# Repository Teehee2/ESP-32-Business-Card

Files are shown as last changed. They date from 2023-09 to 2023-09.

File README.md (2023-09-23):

# ESP-32-Business-Card
Personal Business Card with fully functional ESP-32 and NFC

Latest version V0.2

Friends with version V0.1: PLEASE TAKE NOTE!
DO NOT USE CLIP POINT USB 5V! IT WILL SHORT TO GROUND!

For DIY users:
V0.1 is flawed with mixed up tx/rx traces! Enamel wires need to be flown to use ESP32!
SW1 does not work with resistor R9, it is recommended to short the pads across R9.

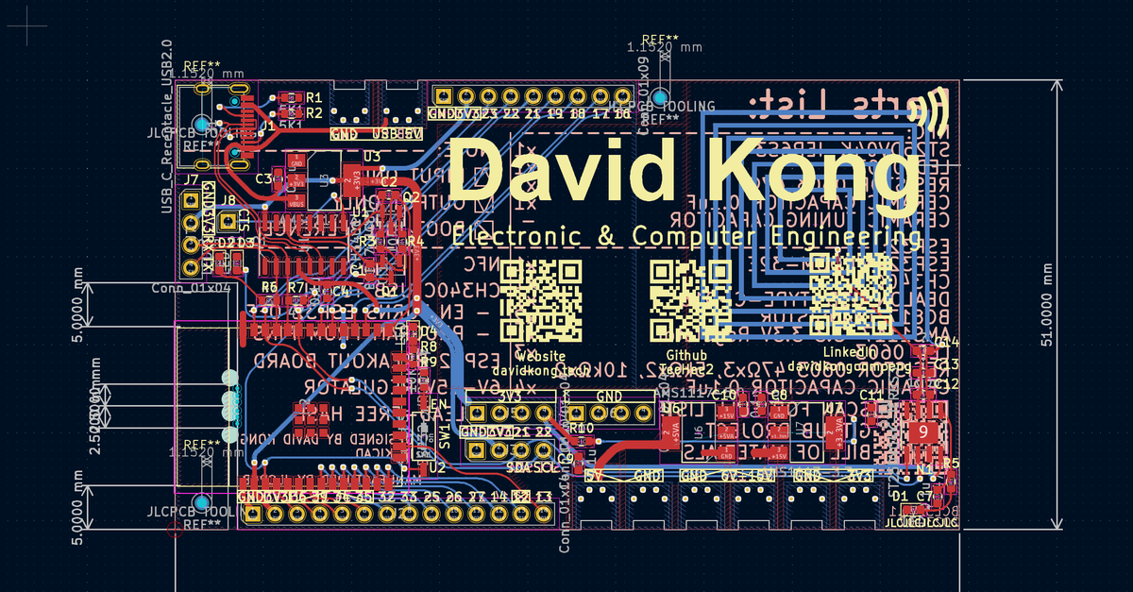
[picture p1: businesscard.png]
ESP32 Business Card


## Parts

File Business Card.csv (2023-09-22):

Source: | D:\PCB projects\Business Card - ESP32\Business Card\Business Card.kicad_sch
Date: | 2023/7/2 22:13:04
Tool: | Eeschema 7.0.5
Generator: | D:\Kicad\7.0\bin\scripting\plugins/bom_csv_grouped_by_value.py
Component Count: | 44
Collated Components:
Item | Qty | Reference(s) | Value | LibPart | Footprint | Datasheet | DNP | Arrow Part Number | Arrow Price/Stock | Height | Manufacturer_Name | Manufacturer_Part_Number | Mouser Part Number | Mouser Price/Stock
1 | 1 | AE1 | ~ | Custom-Symbols:NFC_Antenna | Custom footprints:NFC2
2 | 9 | C1, C2, C3, C4, C7, C8, C9, C10, C11 | 0.1u | Device:C | Capacitor_SMD:C_0201_0603Metric | ~
3 | 1 | C12 | 100p | Device:C | Capacitor_SMD:C_0201_0603Metric | ~
4 | 2 | C13, C14 | ? | Device:C | Capacitor_SMD:C_0201_0603Metric | ~
5 | 4 | D1, D2, D3, D4 | LED | Device:LED | LED_SMD:LED_0201_0603Metric | ~
6 | 1 | J1 | USB_C_Receptacle_USB2.0 | Connector:USB_C_Receptacle_USB2.0 | Connector_USB:USB_C_Receptacle_HRO_TYPE-C-31-M-12 | https://www.usb.org/sites/default/files/documents/usb_type-c.zip
7 | 1 | J2 | Conn_01x14 | Connector_Generic:Conn_01x14 | Custom footprints:PinHeader_1x14_P2.54mm_Vertical_1_No_Silk | ~
8 | 4 | J3, J5, J6, J7 | Conn_01x04 | Connector_Generic:Conn_01x04 | Custom footprints:PinHeader_1x04_P2.54mm_Vertical_No_Silk | ~
9 | 1 | J4 | Conn_01x09 | Connector_Generic:Conn_01x09 | Custom footprints:PinHeader_1x09_P2.54mm_Vertical_No_Silk | ~
10 | 1 | J8 | Conn_01x01 | Connector_Generic:Conn_01x01 | Connector_PinHeader_2.54mm:PinHeader_1x01_P2.54mm_Vertical | ~
11 | 1 | N1 | ST25DV04K-IER6S3 | ST25DV04K-IER6S3:ST25DV04K-IER6S3 | Package_SO:SOIC-8-1EP_3.9x4.9mm_P1.27mm_EP2.41x3.3mm | https://ms.componentsearchengine.com/Datasheets/2/ST25DV04K-IER6S3.pdf |  | ST25DV04K-IER6S3 | https://www.arrow.com/en/products/st25dv04k-ier6s3/stmicroelectronics?region=europe | 1.75 | STMicroelectronics | ST25DV04K-IER6S3 | 511-ST25DV04K-IER6S3 | https://www.mouser.co.uk/ProductDetail/STMicroelectronics/ST25DV04K-IER6S3?qs=xjeEZJU9OeNdtP1j9447OQ%3D%3D
12 | 2 | Q1, Q2 | BC817 | Transistor_BJT:BC817 | Package_TO_SOT_SMD:SOT-23 | https://www.onsemi.com/pub/Collateral/BC818-D.pdf
13 | 2 | R1, R2 | 5K1 | Device:R | Resistor_SMD:R_0201_0603Metric | ~
14 | 3 | R3, R4, R9 | 10K | Device:R | Resistor_SMD:R_0201_0603Metric | ~
15 | 4 | R5, R6, R7, R8 | 47 | Device:R | Resistor_SMD:R_0201_0603Metric | ~
16 | 1 | R10 | 0 | Device:R | Resistor_SMD:R_0201_0603Metric | ~
17 | 1 | SW1 | SW_SPST | Switch:SW_SPST | Button_Switch_SMD:SW_DIP_SPSTx01_Slide_Copal_CHS-01B_W7.62mm_P1.27mm | ~
18 | 1 | U1 | CH340C | Interface_USB:CH340C | Package_SO:SOIC-16_3.9x9.9mm_P1.27mm | https://datasheet.lcsc.com/szlcsc/Jiangsu-Qin-Heng-CH340C_C84681.pdf
19 | 1 | U2 | ESP32-WROOM-E | PCM_Espressif:ESP32-WROOM-E | PCM_Espressif:ESP32-WROOM-32E | https://www.espressif.com/sites/default/files/documentation/esp32-wroom-32e_esp32-wroom-32ue_datasheet_en.pdf
20 | 2 | U3, U7 | AMS1117-3.3 | Regulator_Linear:AMS1117-3.3 | Package_TO_SOT_SMD:SOT-223-3_TabPin2 | http://www.advanced-monolithic.com/pdf/ds1117.pdf
21 | 1 | U6 | AMS1117-5.0 | Regulator_Linear:AMS1117-5.0 | Package_TO_SOT_SMD:SOT-223-3_TabPin2 | http://www.advanced-monolithic.com/pdf/ds1117.pdf

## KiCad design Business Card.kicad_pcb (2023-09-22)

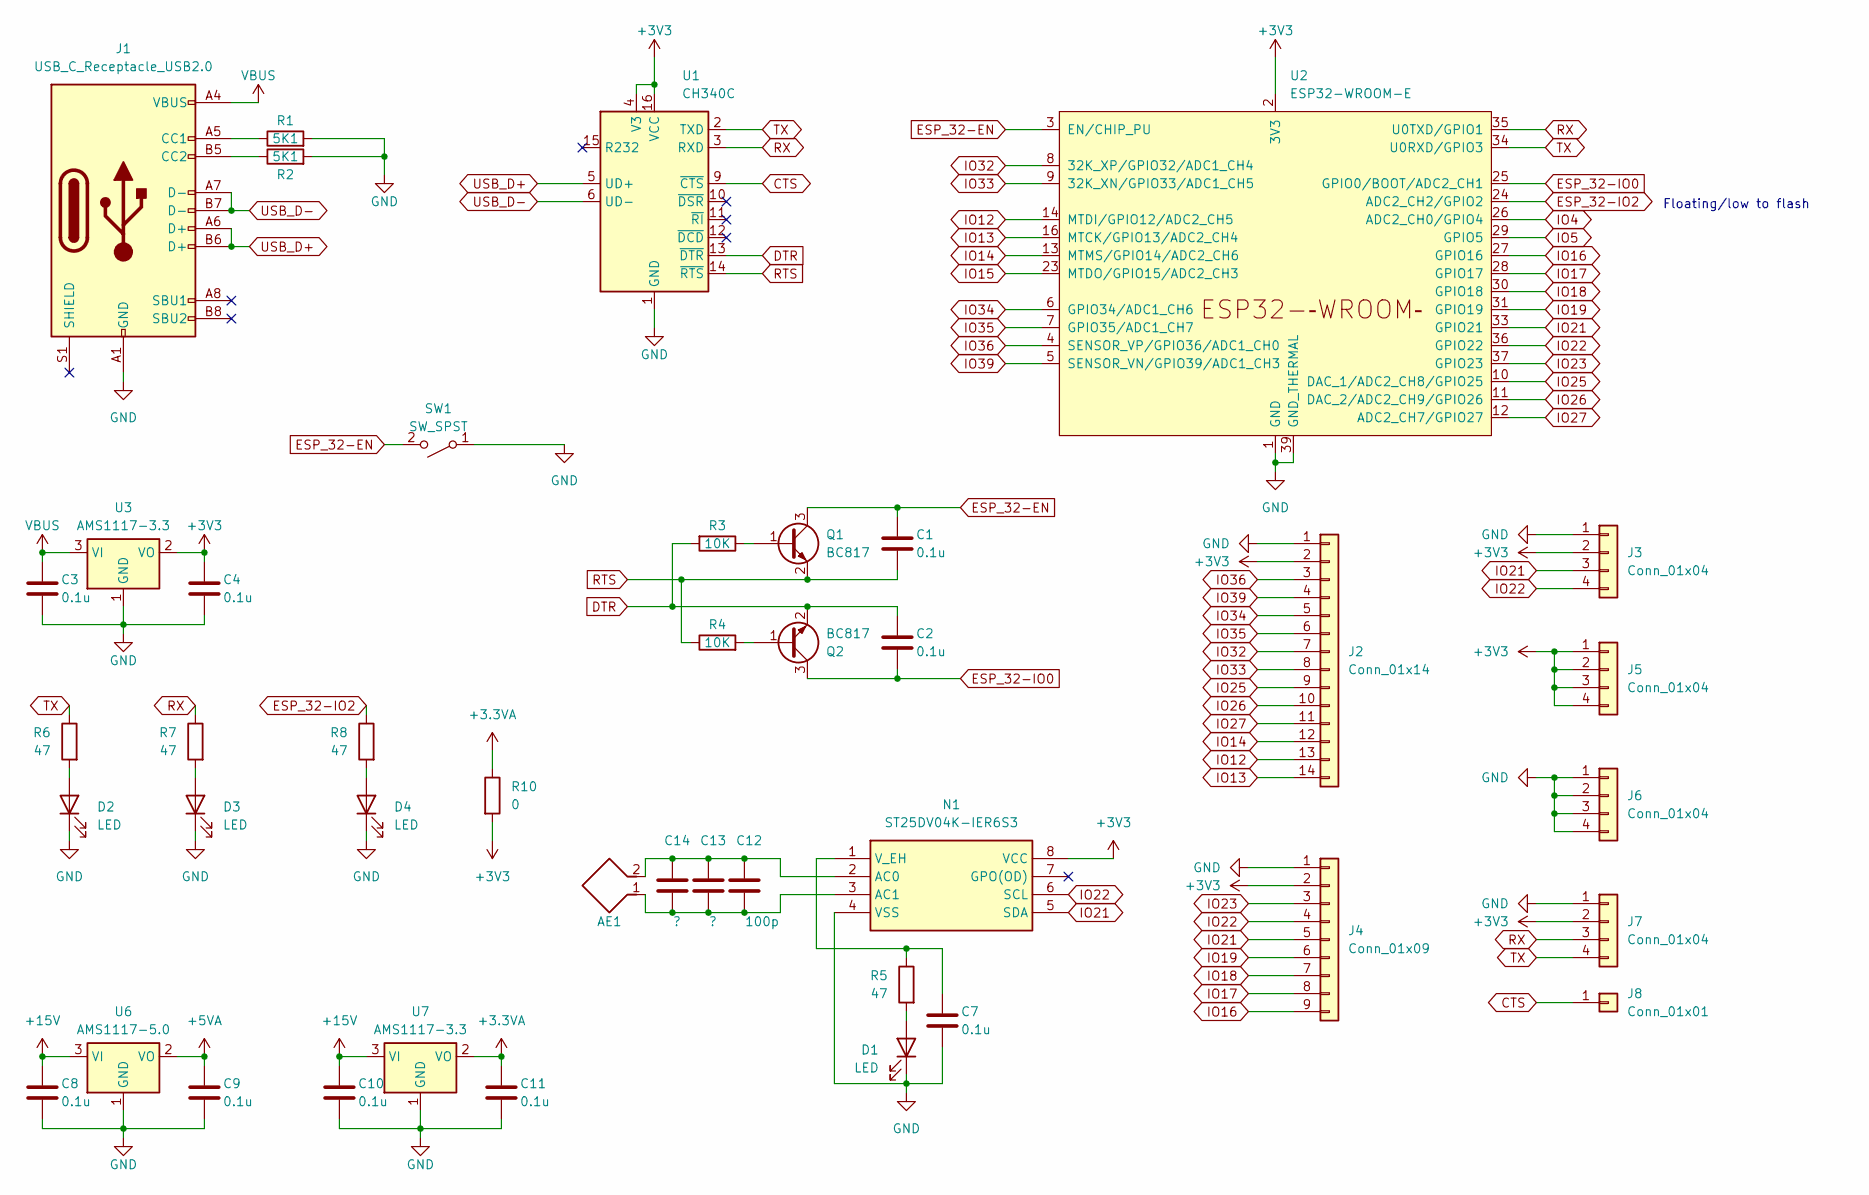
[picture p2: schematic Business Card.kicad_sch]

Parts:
AE1: NFC2
C1, C2, C3, C4, C7, C8, C9, C10, C11: 0.1u; C_0603_1608Metric
C12: 100p; C_0603_1608Metric
C13, C14: ?; C_0603_1608Metric
D1, D2, D3, D4: LED; LED_0603_1608Metric
J1: USB_C_Receptacle_USB2.0; USB_C_Receptacle_HRO_TYPE-C-31-M-12
J2: Conn_01x14; PinHeader_1x14_P2.54mm_Vertical_1_No_Silk
J3, J5, J6, J7: Conn_01x04; PinHeader_1x04_P2.54mm_Vertical_No_Silk
J4: Conn_01x09; PinHeader_1x09_P2.54mm_Vertical_No_Silk
J8: Conn_01x01; PinHeader_1x01_P2.54mm_Vertical_No_Silk
N1: ST25DV04K-IER6S3; SOIC-8-1EP_3.9x4.9mm_P1.27mm_EP2.41x3.3mm; Manufacturer_Part_Number ST25DV04K-IER6S3; Mouser Part Number 511-ST25DV04K-IER6S3
Q1, Q2: BC817; SOT-23
R1, R2: 5K1; R_0603_1608Metric
R3, R4: 10K; R_0603_1608Metric
R5, R6, R7, R8: 47; R_0603_1608Metric
R10: 0; R_0603_1608Metric
SW1: SW_SPST; SW_DIP_SPSTx01_Slide_Copal_CHS-01B_W7.62mm_P1.27mm
U1: CH340C; SOIC-16_3.9x9.9mm_P1.27mm
U2: ESP32-WROOM-E; ESP32-WROOM-32E
U3, U7: AMS1117-3.3; SOT-223-3_TabPin2
U6: AMS1117-5.0; SOT-223-3_TabPin2

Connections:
+3.3VA: C11.1, R10.1, U7.2 (VO)
+3V3: C4.1, J2.2, J3.2, J4.2, J5.1, J5.2, J5.3, J5.4, J7.2, N1.8 (VCC), R10.2, U1.4 (V3), U1.16 (VCC), U2.2 (3V3), U3.2 (VO)
+5VA: C9.1, U6.2 (VO)
+15V: C8.1, C10.1, U6.3 (VI), U7.3 (VI)
CTS: J8.1, U1.9 (~CTS)
DTR: C2.1, Q2.2 (E), R3.2, U1.13 (~DTR)
ESP_32-EN: C1.1, Q1.3 (C), SW1.2 (B), U2.3 (EN/CHIP_PU)
ESP_32-IO0: C2.2, Q2.3 (C), U2.25 (GPIO0/BOOT/ADC2_CH1)
ESP_32-IO2: R8.1, U2.24 (ADC2_CH2/GPIO2)
GND: C3.2, C4.2, C7.2, C8.2, C9.2, C10.2, C11.2, D1.1 (K), D2.1 (K), D3.1 (K), D4.1 (K), J1.A1 (GND), J1.A12 (GND), J1.B1 (GND), J1.B12 (GND), J2.1, J3.1, J4.1, J6.1, J6.2, J6.3, J6.4, J7.1, N1.4 (VSS), R1.2, R2.2, SW1.1 (A), U1.1 (GND), U2.1 (GND), U2.15 (GND), U2.38 (GND), U2.39 (GND_THERMAL), U3.1 (GND), U6.1 (GND), U7.1 (GND); also elsewhere on the board
IO4: U2.26 (ADC2_CH0/GPIO4)
IO5: U2.29 (GPIO5)
IO12: J2.13, U2.14 (MTDI/GPIO12/ADC2_CH5)
IO13: J2.14, U2.16 (MTCK/GPIO13/ADC2_CH4)
IO14: J2.12, U2.13 (MTMS/GPIO14/ADC2_CH6)
IO15: U2.23 (MTDO/GPIO15/ADC2_CH3)
IO16: J4.9, U2.27 (GPIO16)
IO17: J4.8, U2.28 (GPIO17)
IO18: J4.7, U2.30 (GPIO18)
IO19: J4.6, U2.31 (GPIO19)
IO21: J3.3, J4.5, N1.5 (SDA), U2.33 (GPIO21)
IO22: J3.4, J4.4, N1.6 (SCL), U2.36 (GPIO22)
IO23: J4.3, U2.37 (GPIO23)
IO25: J2.9, U2.10 (DAC_1/ADC2_CH8/GPIO25)
IO26: J2.10, U2.11 (DAC_2/ADC2_CH9/GPIO26)
IO27: J2.11, U2.12 (ADC2_CH7/GPIO27)
IO32: J2.7, U2.8 (32K_XP/GPIO32/ADC1_CH4)
IO33: J2.8, U2.9 (32K_XN/GPIO33/ADC1_CH5)
IO34: J2.5, U2.6 (GPIO34/ADC1_CH6)
IO35: J2.6, U2.7 (GPIO35/ADC1_CH7)
IO36: J2.3, U2.4 (SENSOR_VP/GPIO36/ADC1_CH0)
IO39: J2.4, U2.5 (SENSOR_VN/GPIO39/ADC1_CH3)
unnamed: D1.2 (A), R5.2
unnamed: D2.2 (A), R6.2
unnamed: D3.2 (A), R7.2
unnamed: D4.2 (A), R8.2
unnamed: J1.A5 (CC1), R1.1
unnamed: J1.B5 (CC2), R2.1
unnamed: AE1.2, C12.1, C13.1, C14.1, N1.2 (AC0)
unnamed: AE1.1, C12.2, C13.2, C14.2, N1.3 (AC1)
unnamed: C7.1, N1.1 (V_EH), R5.1
unnamed: Q1.1 (B), R3.1
unnamed: Q2.1 (B), R4.2
RTS: C1.2, Q1.2 (E), R4.1, U1.14 (~RTS)
RX: J7.3, R7.1, U1.3 (RXD), U2.35 (U0TXD/GPIO1)
TX: J7.4, R6.1, U1.2 (TXD), U2.34 (U0RXD/GPIO3)
USB_D+: J1.A6 (D+), J1.B6 (D+), U1.5 (UD+)
USB_D-: J1.A7 (D-), J1.B7 (D-), U1.6 (UD-)
VBUS: C3.1, J1.A4 (VBUS), J1.A9 (VBUS), J1.B4 (VBUS), J1.B9 (VBUS), U3.3 (VI)

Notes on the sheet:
Floating/low to flash

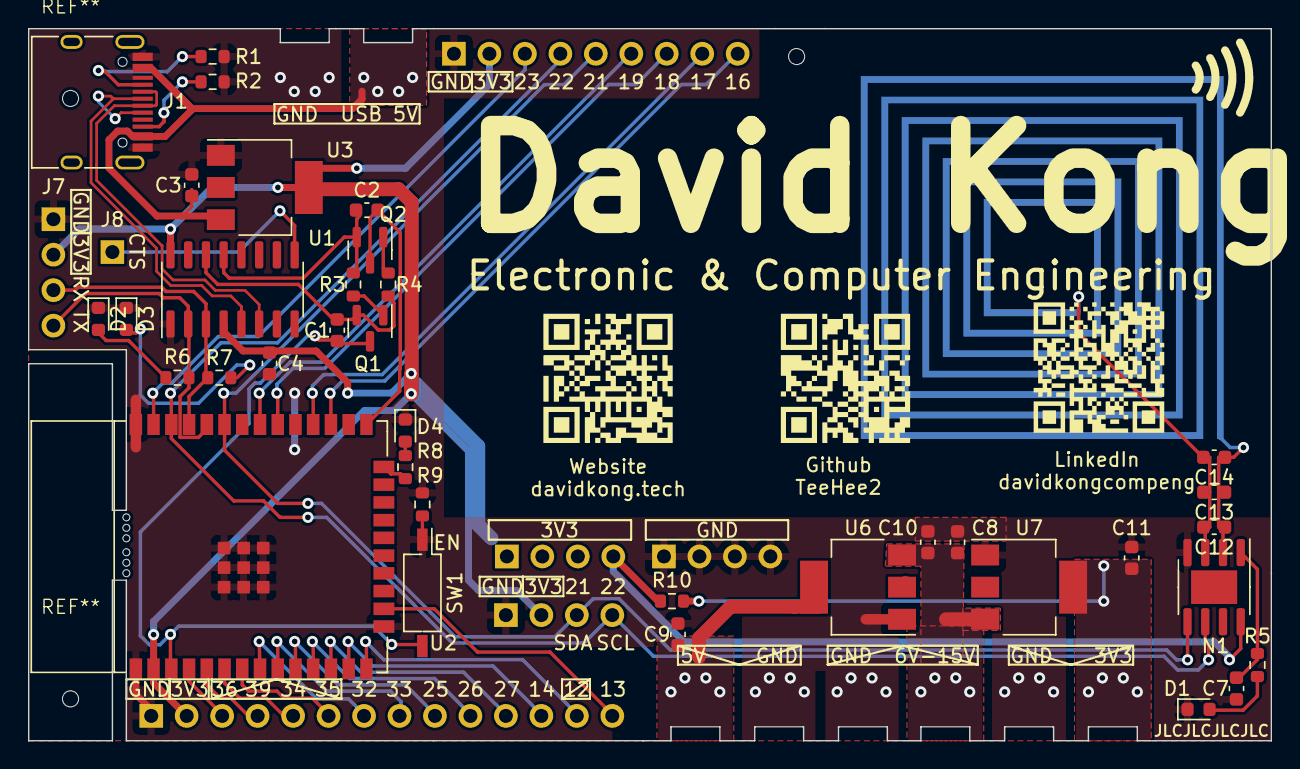
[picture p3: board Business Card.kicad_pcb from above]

Board: 2 copper layers, 89.0 x 51.0 mm, 46 parts (1 on the bottom side), 46 nets.

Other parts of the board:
R9: 10K; R_0603_1608Metric
mouse-bite-2mm-slot, mouse-bite-2mm-slot#2: VAL**; mouse-bite-2mm-slot_1

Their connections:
GND: R9.1; also elsewhere on the board
